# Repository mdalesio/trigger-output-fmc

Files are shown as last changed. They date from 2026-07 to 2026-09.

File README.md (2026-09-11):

# Trigger Output FMC

A single width HPC FMC board which provides 16 low jitter TTL outputs,
along with two Si5394 jitter cleaners with outputs connected to the MGTREF capable
when matched with the [LBL Marble](https://github.com/BerkeleyLab/Marble) FMC carrier.

This design is Open Hardware created by Osprey DCS and published under the terms of the
[CERN Open Hardware Licence Version 2 - Strongly Reciprocal](cern_ohl_s_v2.txt) license.

This repository contains KiCad 9.0.4 design files.

- [Data sheet](datasheet.md)
- [Current generated](https://osprey-dcs.github.io/trigger-output-fmc/)
  - [Schematic](https://osprey-dcs.github.io/trigger-output-fmc/trigger-output-fmc-schematic.pdf)
  - [BoM](https://osprey-dcs.github.io/trigger-output-fmc/trigger-output-fmc-bom.csv)
  - [STeP model](https://osprey-dcs.github.io/trigger-output-fmc/3D/trigger-output-fmc-3D.step)

## Block Diagram

Block diagra

## Status

Revision 1.0 produced and tested.

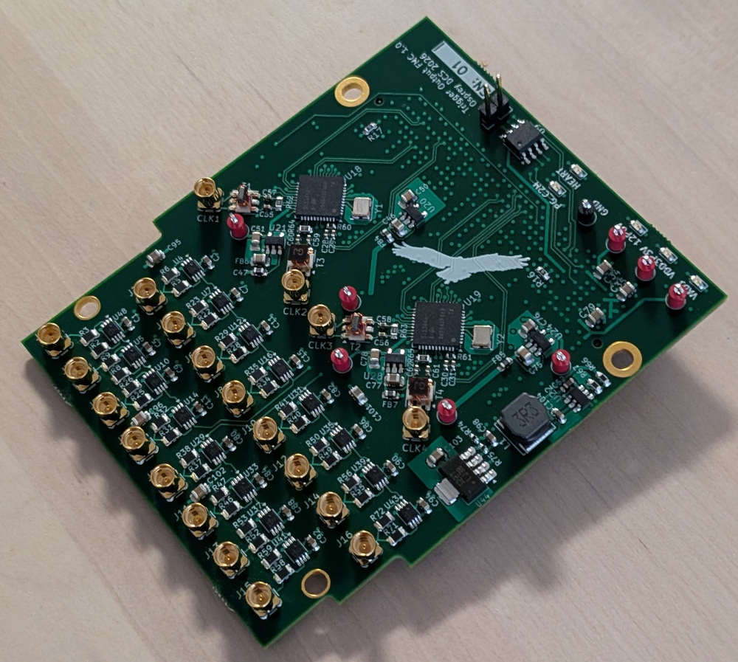
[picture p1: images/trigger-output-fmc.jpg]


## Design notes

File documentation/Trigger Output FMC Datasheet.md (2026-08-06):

# Trigger Output FMC Datasheet Draft
## Board Overview
The Trigger Output FMC board is a standard VITA 57.1 FMC HPC form factor board. [^1]
The board provides 2 independent Skyworks Solutions Si5394 Jitter Cleaners that recieve clocks though the FMC's M2C clock lines. Each Si5394 then outputs 4 copies of the recovered clock; 1 to the FMC's MGT clock, 1 to a FMC's C2M clock and 2 to SMA test ports on the board. The board has sixteen 50 ohm drive TTL-compatible digital outputs designed for low jitter. The outputs are provided as MMCX coaxial connectors.

[^1]:  The board can be used in a VITA 57.1 FMC LPC application but is limited to a single clock/timing domain. 
## Key components

- Skyworks Solutions Si5394 Jitter Attenuator
	- Ultra-low phase jitter of 100 fs RMS
	- Input frequency range - 8 kHz to 750 MHz
	- Output frequency range - 100 Hz to 1028 MHz
- Texas Instruments TLV3601 High-Speed Comparator
	- 4 ps RMS Jitter over 10Hz – 50MHz
- Texas Instruments SN74LVC2G126 Dual Bus Buffer Gate With 3-State Outputs
	- Can drive 50 ohm back-terminated TTL loads [^2]

[^2]:  See PubMed Central article PMC8342968 [link](https://pmc.ncbi.nlm.nih.gov/articles/PMC8342968/)
## Board Architecture
![[BlockDiagram.png|501]]

## Technical Specifications
### Nominal Performance
Channel-to-Channel Output Jitter: < 20pSec RMS
Event Clock Frequency: 50MHz - 250MHz;
16x SMA connectors; 50Ω drive capable; LVTTL

### Absolute Performance
Ambient Temperature: 0°C - 40°C
Digital Output drive current: 100mA max
Event Clock Rate: 50MHz - 250MHz
Event Bitrate: 1Gbps - 5Gbps
Number of user-configurable events: 255

## To include at a later date
- Nominal Testing data
- ? Theory of Operation for Output trigger
- ? Specifications for on-board power switcher and LDOs

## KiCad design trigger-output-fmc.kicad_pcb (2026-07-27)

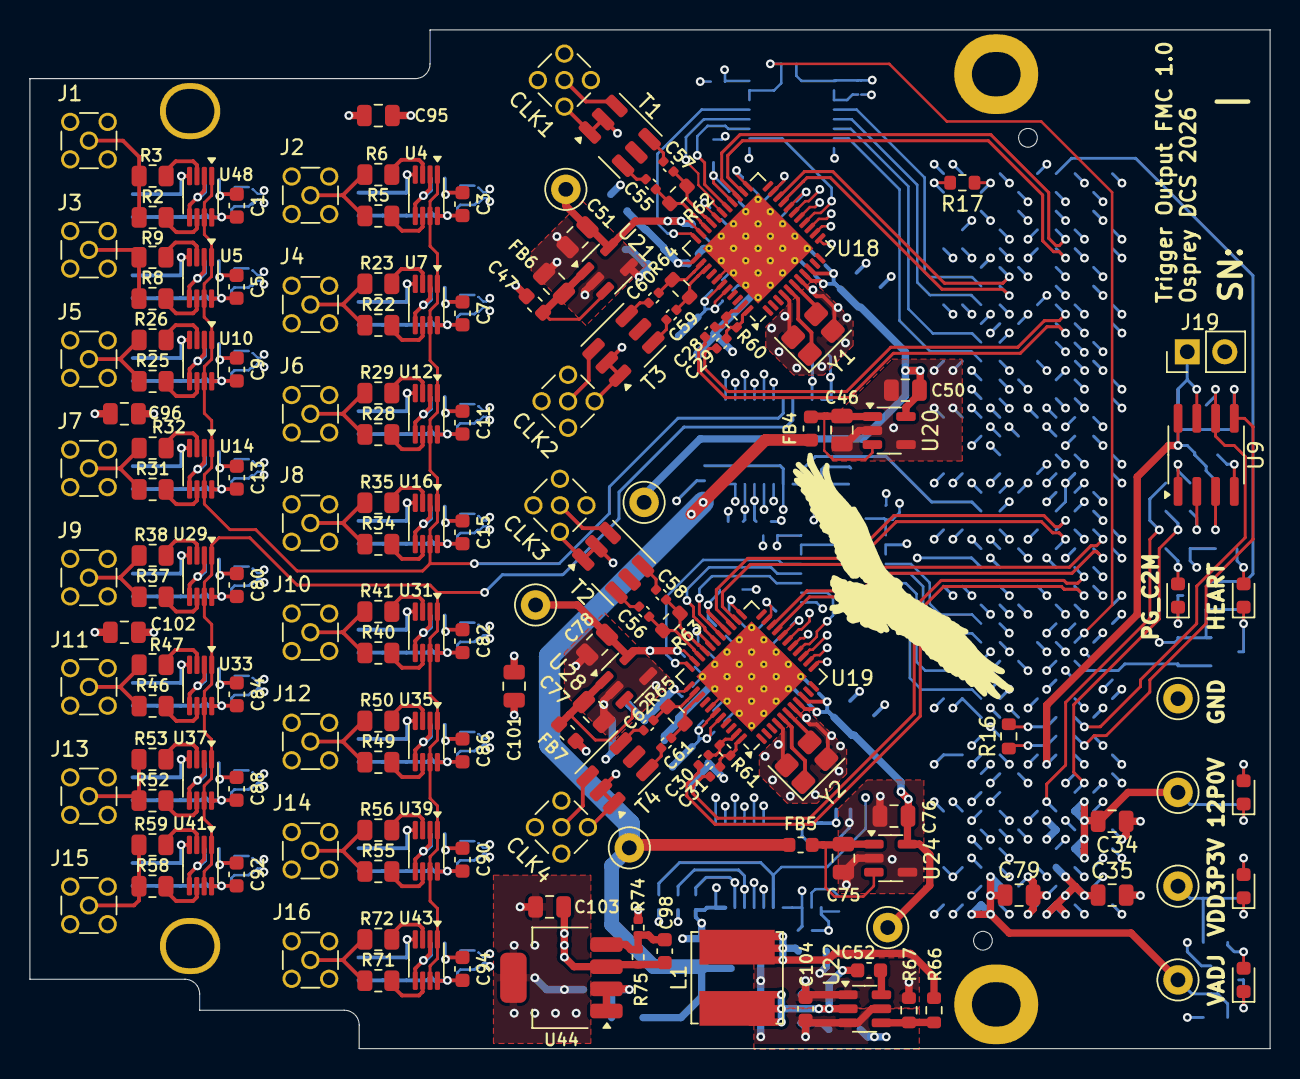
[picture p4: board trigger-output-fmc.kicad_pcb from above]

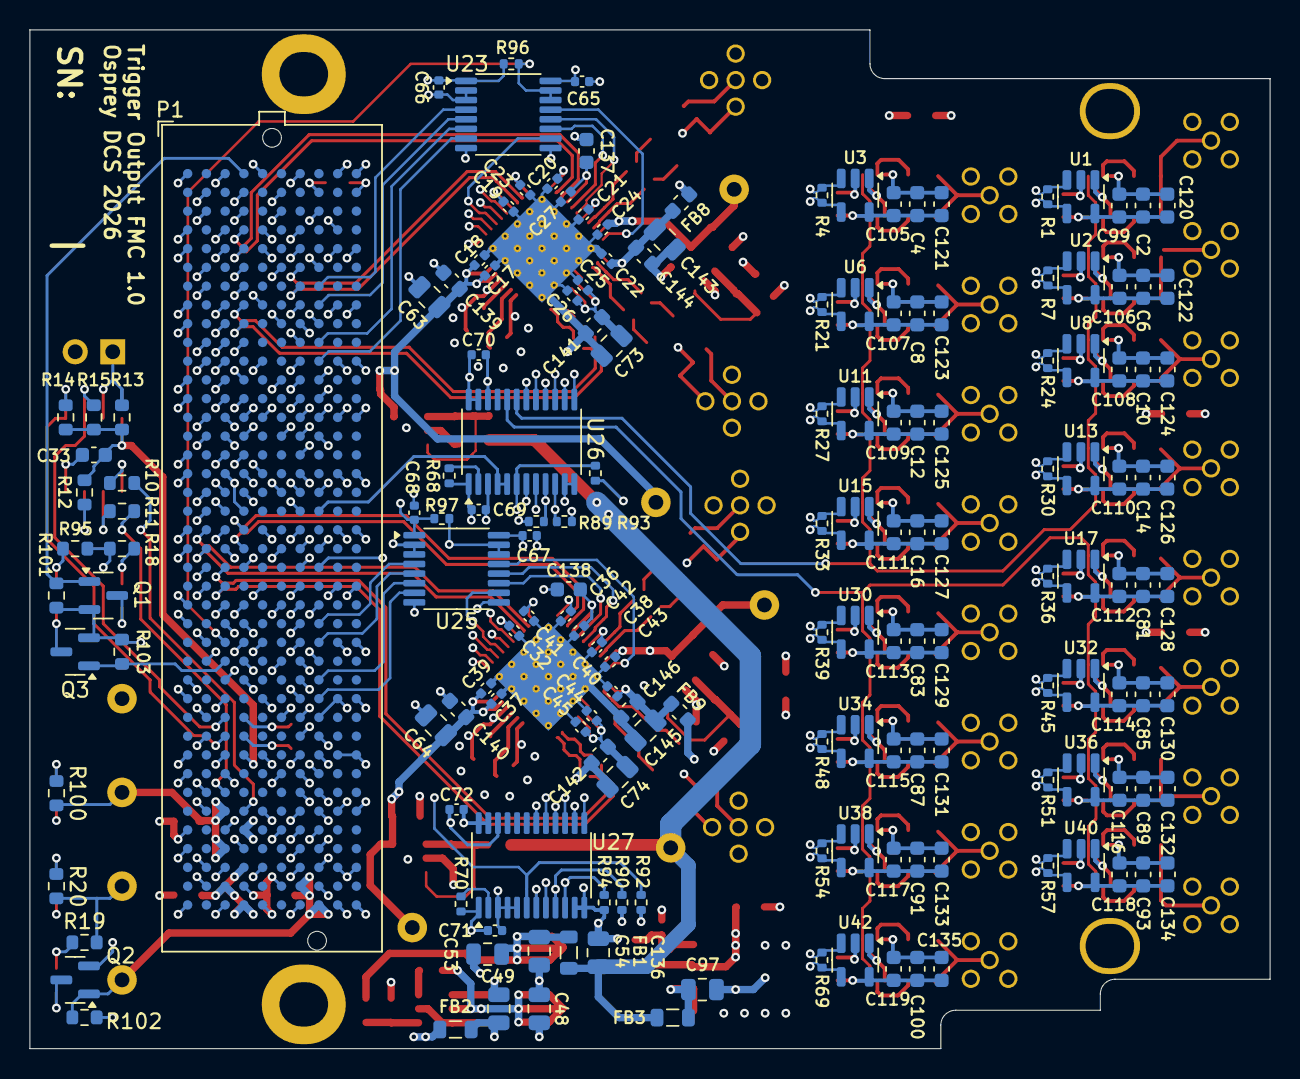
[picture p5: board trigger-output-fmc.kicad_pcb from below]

Board: 8 copper layers, 84.0 x 69.0 mm, 335 parts (168 on the bottom side), 226 nets.

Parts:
C1, C2, C3, C4, C5, C6, C7, C8, C9, C10, C11, C12, C13, C14, C15, C16, C52, C80, C81, C82, C83, C84, C85, C86, C87, C88, C89, C90, C91, C92, C93, C94, C100, C104: 100nF; C_0603_1608Metric
C17, C18, C19, C20, C21, C22, C23, C24, C25, C26, C27, C28, C29, C30, C31, C32, C36, C37, C38, C39, C40, C41, C42, C43, C44, C45, C55, C56, C57, C58, C59, C60, C61, C62, C65, C66, C67, C68, C69, C70, C71, C72: 100nF; C_0402_1005Metric
C33, C120, C121, C122, C123, C124, C125, C126, C127, C128, C129, C130, C131, C132, C133, C134, C135, C137, C138, C139, C140, C141, C142, C144, C146: 1uF; C_0603_1608Metric
C34, C35, C53, C54, C79, C136: 22uF; C_0805_2012Metric
C46, C47, C48, C49, C50, C51, C63, C64, C73, C74, C75, C76, C77, C78, C95, C96, C97, C101, C102, C103, C143, C145: 10uF; C_0805_2012Metric
C98: 62pF; C_0603_1608Metric
C99, C105, C106, C107, C108, C109, C110, C111, C112, C113, C114, C115, C116, C117, C118, C119: 10nF; C_0603_1608Metric
CLK1, CLK2, CLK3, CLK4: MMCX; MMCX_Molex_73415-1471_Vertical
D1, D2, D3, D4, D5: Green; LED_0603_1608Metric
FB1, FB2, FB3: 300@100MHz; L_0805_2012Metric
FB4, FB5, FB6, FB7, FB8, FB9: 120@100MHz; L_0603_1608Metric
H1, H2: MountingHole; MountingHole_3.0mm_M2.5_Pad_3.3mm_UniversalMarbleSlot
H3, H4: MountingHole; MountingHole_3.0mm_3.8mm_Pad_3.3mm_UniversalMarbleSlot
J1, J2, J3, J4, J5, J6, J7, J8, J9, J10, J11, J12, J13, J14, J15, J16: MMCX; MMCX_Molex_73415-1471_Vertical
J19: WP Jumper; PinHeader_1x02_P2.54mm_Vertical
L1: SRN6045TA-3R3Y; L_Bourns_SRN6045TA
Logo1: Osprey Logo; Logo_2X
P1: ASP-134488-01; Samtec_FMC_ASP-134602-01_10x40_P1.27mm_Vertical
Q1, Q2, Q3: FDN335N; SOT-23
R1, R4, R7, R21, R24, R27, R30, R33, R36, R39, R45, R48, R51, R54, R57, R60, R61, R69: 100R; R_0402_1005Metric
R2, R3, R5, R6, R8, R9, R22, R23, R25, R26, R28, R29, R31, R32, R34, R35, R37, R38, R40, R41, R46, R47, R49, R50, R52, R53, R55, R56, R58, R59, R71, R72: 88.7R; R_0805_2012Metric
R10, R11, R12, R14, R15: 4.75k; R_0603_1608Metric
R13: 11.5k; R_0603_1608Metric
R16, R17: 0R; R_0603_1608Metric
R18, R19, R20, R95: 1k; R_0603_1608Metric
R62, R63, R64, R65: 100R; R_0603_1608Metric
R66: 107k; R_0603_1608Metric
R67: 17.4k; R_0603_1608Metric
R68, R70, R89, R90, R91, R92, R93, R94, R96, R97: 4.75k; R_0402_1005Metric
R74: 18k; R_0402_1005Metric
R75: 56k; R_0402_1005Metric
R100: 8.2k; R_0603_1608Metric
R101, R102, R103: 100k; R_0603_1608Metric
T1, T2, T3, T4: TCM2-43X+; Mini-Circuits_DB1627_rounded_pads
TP1: Keystone5001; TestPoint_Keystone_5000-5004_Miniature
TP2, TP3, TP4, TP5, TP6, TP7, TP8, TP9: Keystone5000; TestPoint_Keystone_5000-5004_Miniature
U1, U2, U3, U6, U8, U11, U13, U15, U17, U30, U32, U34, U36, U38, U40, U42: TLV3601; SOT-23-5
U4, U5, U7, U10, U12, U14, U16, U29, U31, U33, U35, U37, U39, U41, U43, U48: SN74LVC2G126; VSSOP-8_2.3x2mm_P0.5mm
U9: AT24C64D; SOIC-8_3.9x4.9mm_P1.27mm
U18, U19: SI5394; QFN-44-1EP_7x7mm_P0.5mm_EP5.2x5.2mm_ThermalVias
U20, U24: TLV75733PDBV; SOT-23-5
U21, U28: TLV75718PDBV; SOT-23-5
U22: TPS563200; SOT-23-6
U23, U25: 74AVC4T245; TSSOP-16_4.4x5mm_P0.65mm
U26, U27: 74LVC8T245; TSSOP-24_4.4x7.8mm_P0.65mm
U44: LP3855EMP-ADJ/NOPB; SOT-223-5
Y1, Y2: CX3225SB48000D0FPJC1; Crystal_SMD_Abracon_ABM8AIG-4Pin_3.2x2.5mm

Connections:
3P3VAUX: C33.1, P1.D32, R12.1, R13.1, R14.1, R15.1, U9.8 (VCC)
+12V_FMC: C34.1, FB2.1, P1.C35, P1.C37, R100.2, TP2.1
/Digital IO/D_Output0.N: P1.G13, R1.2, U1.4 (-)
/Digital IO/D_Output0.P: P1.G12, R1.1, U1.3 (+)
/Digital IO/D_Output1.N: P1.H14, R4.2, U3.4 (-)
/Digital IO/D_Output1.P: P1.H13, R4.1, U3.3 (+)
/Digital IO/D_Output2.N: P1.G16, R7.2, U2.4 (-)
/Digital IO/D_Output2.P: P1.G15, R7.1, U2.3 (+)
/Digital IO/D_Output3.N: P1.D15, R21.2, U6.4 (-)
/Digital IO/D_Output3.P: P1.D14, R21.1, U6.3 (+)
/Digital IO/D_Output4.N: P1.C15, R24.2, U8.4 (-)
/Digital IO/D_Output4.P: P1.C14, R24.1, U8.3 (+)
/Digital IO/D_Output5.N: P1.G19, R27.2, U11.4 (-)
/Digital IO/D_Output5.P: P1.G18, R27.1, U11.3 (+)
/Digital IO/D_Output6.N: P1.D18, R30.2, U13.4 (-)
/Digital IO/D_Output6.P: P1.D17, R30.1, U13.3 (+)
/Digital IO/D_Output7.N: P1.C19, R33.2, U15.4 (-)
/Digital IO/D_Output7.P: P1.C18, R33.1, U15.3 (+)
/Digital IO/D_Output8.N: P1.G22, R36.2, U17.4 (-)
/Digital IO/D_Output8.P: P1.G21, R36.1, U17.3 (+)
/Digital IO/D_Output9.N: P1.G28, R39.2, U30.4 (-)
/Digital IO/D_Output9.P: P1.G27, R39.1, U30.3 (+)
/Digital IO/D_Output10.N: P1.G31, R45.2, U32.4 (-)
/Digital IO/D_Output10.P: P1.G30, R45.1, U32.3 (+)
/Digital IO/D_Output11.N: P1.H32, R48.2, U34.4 (-)
/Digital IO/D_Output11.P: P1.H31, R48.1, U34.3 (+)
/Digital IO/D_Output12.N: P1.G34, R51.2, U36.4 (-)
/Digital IO/D_Output12.P: P1.G33, R51.1, U36.3 (+)
/Digital IO/D_Output13.N: P1.H35, R54.2, U38.4 (-)
/Digital IO/D_Output13.P: P1.H34, R54.1, U38.3 (+)
/Digital IO/D_Output14.N: P1.H38, R57.2, U40.4 (-)
/Digital IO/D_Output14.P: P1.H37, R57.1, U40.3 (+)
/Digital IO/D_Output15.N: P1.G37, R69.2, U42.4 (-)
/Digital IO/D_Output15.P: P1.G36, R69.1, U42.3 (+)
/Digital IO/OE_A: U4.1 (1OE), U4.7 (2OE), U5.1 (1OE), U5.7 (2OE), U7.1 (1OE), U7.7 (2OE), U10.1 (1OE), U10.7 (2OE), U12.1 (1OE), U12.7 (2OE), U14.1 (1OE), U14.7 (2OE), U16.1 (1OE), U16.7 (2OE), U26.19 (B3), U48.1 (1OE), U48.7 (2OE)
/Digital IO/OE_B: U26.20 (B2), U29.1 (1OE), U29.7 (2OE), U31.1 (1OE), U31.7 (2OE), U33.1 (1OE), U33.7 (2OE), U35.1 (1OE), U35.7 (2OE), U37.1 (1OE), U37.7 (2OE), U39.1 (1OE), U39.7 (2OE), U41.1 (1OE), U41.7 (2OE), U43.1 (1OE), U43.7 (2OE)
/Digital IO/Switched_5P45V: C136.1, FB1.2, FB3.1, FB4.1, FB5.1, TP8.1
/Digital IO/VCC: C1.2, C2.2, C3.2, C4.2, C5.2, C6.2, C7.2, C8.2, C9.2, C10.2, C11.2, C12.2, C13.2, C14.2, C15.2, C16.2, C80.2, C81.2, C82.2, C83.2, C84.2, C85.2, C86.2, C87.2, C88.2, C89.2, C90.2, C91.2, C92.2, C93.2, C94.2, C95.1, C96.1, C98.1, C99.2, C100.2, C101.1, C102.1, C103.1, C105.2, C106.2, C107.2, C108.2, C109.2, C110.2, C111.2, C112.2, C113.2, C114.2, C115.2, C116.2, C117.2, C118.2, C119.2, C120.2, C121.2, C122.2, C123.2, C124.2, C125.2, C126.2, C127.2, C128.2, C129.2, C130.2, C131.2, C132.2, C133.2, C134.2, C135.2, R75.2, U1.5 (V+), U2.5 (V+), U3.5 (V+), U4.8 (V_{CC}), U5.8 (V_{CC}), U6.5 (V+), U7.8 (V_{CC}), U8.5 (V+), U10.8 (V_{CC}), U11.5 (V+), U12.8 (V_{CC}), U13.5 (V+), U14.8 (V_{CC}), U15.5 (V+), U16.8 (V_{CC}), U17.5 (V+), U29.8 (V_{CC}), U30.5 (V+), U31.8 (V_{CC}), U32.5 (V+), U33.8 (V_{CC}), U34.5 (V+), U35.8 (V_{CC}), U36.5 (V+), U37.8 (V_{CC}), U38.5 (V+), U39.8 (V_{CC}), U40.5 (V+), U41.8 (V_{CC}), U42.5 (V+), U43.8 (V_{CC}), U44.3 (Vout), U48.8 (V_{CC})
/Digital IO/out_buffer0/Out: J1.1 (In), R2.2, R3.2
/Digital IO/out_buffer1/Out: J2.1 (In), R5.2, R6.2
/Digital IO/out_buffer2/Out: J3.1 (In), R8.2, R9.2
/Digital IO/out_buffer3/Out: J4.1 (In), R22.2, R23.2
/Digital IO/out_buffer4/Out: J5.1 (In), R25.2, R26.2
/Digital IO/out_buffer5/Out: J6.1 (In), R28.2, R29.2
/Digital IO/out_buffer6/Out: J7.1 (In), R31.2, R32.2
/Digital IO/out_buffer7/Out: J8.1 (In), R34.2, R35.2
/Digital IO/out_buffer8/Out: J9.1 (In), R37.2, R38.2
/Digital IO/out_buffer9/Out: J10.1 (In), R40.2, R41.2
/Digital IO/out_buffer10/Out: J11.1 (In), R46.2, R47.2
/Digital IO/out_buffer11/Out: J12.1 (In), R49.2, R50.2
/Digital IO/out_buffer12/Out: J13.1 (In), R52.2, R53.2
/Digital IO/out_buffer13/Out: J14.1 (In), R55.2, R56.2
/Digital IO/out_buffer14/Out: J15.1 (In), R58.2, R59.2
/Digital IO/out_buffer15/Out: J16.1 (In), R71.2, R72.2
/FMC/Cleaned_CLK_0.N: P1.G7, U18.19 (~OUT0)
/FMC/Cleaned_CLK_0.P: P1.G6, U18.20 (Out0)
/FMC/Cleaned_CLK_1.N: P1.D21, U19.24 (~OUT1)
/FMC/Cleaned_CLK_1.P: P1.D20, U19.25 (Out1)
/FMC/Cleaner_Fault_0.INTR: P1.H7, U23.4 (A1)
/FMC/Cleaner_Fault_0.LOL: P1.H10, U23.6 (A3)
/FMC/Cleaner_Fault_0.LOS_XO: P1.H8, U23.5 (A2)
/FMC/Cleaner_Fault_1.INTR: P1.H25, U25.4 (A1)
/FMC/Cleaner_Fault_1.LOL: P1.H28, U25.6 (A3)
/FMC/Cleaner_Fault_1.LOS_XO: P1.H26, U25.5 (A2)
/FMC/Cleaner_SPI_0.CLK: P1.C10, U26.8 (A6)
/FMC/Cleaner_SPI_0.CS: P1.G10, R89.1, U26.9 (A7)
/FMC/Cleaner_SPI_0.OE: P1.D12, R91.1, U26.6 (A4)
/FMC/Cleaner_SPI_0.SDI: P1.C11, U26.7 (A5)
/FMC/Cleaner_SPI_0.SDO: P1.H11, U23.7 (A4)
/FMC/Cleaner_SPI_1.CLK: P1.D24, U27.8 (A6)
/FMC/Cleaner_SPI_1.CS: P1.G25, R90.1, U27.9 (A7)
/FMC/Cleaner_SPI_1.OE: P1.D27, R92.1, U27.6 (A4)
/FMC/Cleaner_SPI_1.SDI: P1.D26, U27.7 (A5)
/FMC/Cleaner_SPI_1.SDO: P1.H29, U25.7 (A4)
/FMC/Cleaner_~OE_0: P1.C26, R96.1, U23.14 (OE), U23.15 (OE)
/FMC/Cleaner_~OE_1: P1.H22, R97.1, U25.14 (OE), U25.15 (OE)
/FMC/Cleaner_~RST_0: P1.G9, R93.2, U26.10 (A8)
/FMC/Cleaner_~RST_1: P1.G24, R94.2, U27.10 (A8)
/FMC/EEPROM_GA0: P1.C34, R11.1
/FMC/EEPROM_GA1: P1.D35, R10.1
/FMC/EEPROM_SCL: P1.C30, R15.2, U9.6 (SCL)
/FMC/EEPROM_SDA: P1.C31, R14.2, U9.5 (SDA)
/FMC/FMC_GBTCLK0.N: P1.D5, U18.24 (~OUT1)
/FMC/FMC_GBTCLK0.P: P1.D4, U18.25 (Out1)
/FMC/FMC_GBTCLK1.N: P1.B21, U19.19 (~OUT0)
/FMC/FMC_GBTCLK1.P: P1.B20, U19.20 (Out0)
/FMC/OE_Digital_Outputs: P1.H19, U26.4 (A2), U26.5 (A3)
/FMC/Recovered_CLK_0.N: C29.1, P1.D8
/FMC/Recovered_CLK_0.P: C28.1, P1.D9
/FMC/Recovered_CLK_1.N: C31.1, P1.C22
/FMC/Recovered_CLK_1.P: C30.1, P1.C23
/Jitter Cleaner0/Cleaned_CLK2.N: C57.1, R62.2, U18.30 (~OUT2)
/Jitter Cleaner0/Cleaned_CLK2.P: C55.1, R62.1, U18.31 (Out2)
/Jitter Cleaner0/Cleaned_CLK3.N: C60.1, R64.2, U18.35 (~OUT3)
/Jitter Cleaner0/Cleaned_CLK3.P: C59.1, R64.1, U18.36 (Out3)
/Jitter Cleaner0/Control.INTR: U18.33 (~INTR), U23.13 (B1)
/Jitter Cleaner0/Control.LOL: U18.27 (~LOL), U23.11 (B3)
/Jitter Cleaner0/Control.LOS_XO: U18.28 (~LOS_XAXB), U23.12 (B2)
/Jitter Cleaner0/Control.OE: U18.12 (~OE), U26.18 (B4)
/Jitter Cleaner0/Control.RST: U18.17 (~RST), U26.14 (B8)
/Jitter Cleaner0/Control.SPI_CLK: U18.14 (SCLK), U26.16 (B6)
/Jitter Cleaner0/Control.SPI_CS: U18.16 (A0/~CS), U26.15 (B7)
/Jitter Cleaner0/Control.SPI_SDI: U18.13 (SDA/SDIO), U26.17 (B5)
/Jitter Cleaner0/Control.SPI_SDO: U18.15 (A1/SDO), U23.10 (B4)
/Jitter Cleaner0/In0.N: C29.2, R60.2, U18.44 (~IN0)
/Jitter Cleaner0/In0.P: C28.2, R60.1, U18.43 (In0)
/Jitter Cleaner0/VDD: C23.1, C24.1, C25.1, C26.1, C51.1, C73.1, C141.1, TP5.1, U18.21 (VDD), U18.32 (VDD), U18.39 (VDD), U18.40 (VDD), U21.5 (OUT)
/Jitter Cleaner0/VDDA: C17.1, C18.1, C50.1, C63.1, C139.1, TP7.1, U18.8 (VDDA), U18.9 (VDDA), U20.5 (OUT)
/Jitter Cleaner1/Cleaned_CLK2.N: C58.1, R63.2, U19.30 (~OUT2)
/Jitter Cleaner1/Cleaned_CLK2.P: C56.1, R63.1, U19.31 (Out2)
/Jitter Cleaner1/Cleaned_CLK3.N: C62.1, R65.2, U19.35 (~OUT3)
/Jitter Cleaner1/Cleaned_CLK3.P: C61.1, R65.1, U19.36 (Out3)
/Jitter Cleaner1/Control.INTR: U19.33 (~INTR), U25.13 (B1)
/Jitter Cleaner1/Control.LOL: U19.27 (~LOL), U25.11 (B3)
/Jitter Cleaner1/Control.LOS_XO: U19.28 (~LOS_XAXB), U25.12 (B2)
/Jitter Cleaner1/Control.OE: U19.12 (~OE), U27.18 (B4)
/Jitter Cleaner1/Control.RST: U19.17 (~RST), U27.14 (B8)
/Jitter Cleaner1/Control.SPI_CLK: U19.14 (SCLK), U27.16 (B6)
/Jitter Cleaner1/Control.SPI_CS: U19.16 (A0/~CS), U27.15 (B7)
/Jitter Cleaner1/Control.SPI_SDI: U19.13 (SDA/SDIO), U27.17 (B5)
/Jitter Cleaner1/Control.SPI_SDO: U19.15 (A1/SDO), U25.10 (B4)
/Jitter Cleaner1/In0.N: C31.2, R61.2, U19.44 (~IN0)
/Jitter Cleaner1/In0.P: C30.2, R61.1, U19.43 (In0)
/Jitter Cleaner1/VDD: C41.1, C43.1, C44.1, C45.1, C74.1, C78.1, C142.1, TP9.1, U19.21 (VDD), U19.32 (VDD), U19.39 (VDD), U19.40 (VDD), U28.5 (OUT)
/Jitter Cleaner1/VDDA: C37.1, C39.1, C64.1, C76.1, C140.1, TP6.1, U19.8 (VDDA), U19.9 (VDDA), U24.5 (OUT)
GND: C1.1, C2.1, C3.1, C4.1, C5.1, C6.1, C7.1, C8.1, C9.1, C10.1, C11.1, C12.1, C13.1, C14.1, C15.1, C16.1, C17.2, C18.2, C19.2, C20.2, C21.2, C22.2, C23.2, C24.2, C25.2, C26.2, C27.2, C32.2, C33.2, C34.2, C35.2, C36.2, C37.2, C38.2, C39.2, C40.2, C41.2, C42.2, C43.2, C44.2, C45.2, C46.2, C47.2, C48.2, C49.2, C50.2, C51.2, C53.2, C54.2, C63.2, C64.2, C65.1, C66.1, C67.1, C68.1, C69.1, C70.1, C71.1, C72.1, C73.2, C74.2, C75.2, C76.2, C77.2, C78.2, C79.2, C80.1, C81.1, C82.1, C83.1, C84.1, C85.1, C86.1, C87.1, C88.1, C89.1, C90.1, C91.1, C92.1, C93.1, C94.1, C95.2, C96.2, C97.2, C99.1, C100.1, C101.2, C102.2, C103.2, C104.1, C105.1, C106.1, C107.1, C108.1, C109.1, C110.1, C111.1, C112.1, C113.1, C114.1, C115.1, C116.1, C117.1, C118.1, C119.1, C120.1, C121.1, C122.1, C123.1, C124.1, C125.1, C126.1, C127.1, C128.1, C129.1, C130.1, C131.1, C132.1, C133.1, C134.1, C135.1, C136.2, C137.2, C138.2, C139.2, C140.2, C141.2, C142.2, C143.2, C144.2, C145.2, C146.2, CLK1.2 (Ext), CLK2.2 (Ext), CLK3.2 (Ext), CLK4.2 (Ext), D3.1 (K), D5.1 (K), H1.1, H2.1, H3.1, H4.1, J1.2 (Ext), J2.2 (Ext), J3.2 (Ext), J4.2 (Ext), J5.2 (Ext), J6.2 (Ext), J7.2 (Ext), J8.2 (Ext), J9.2 (Ext), J10.2 (Ext), J11.2 (Ext), J12.2 (Ext), J13.2 (Ext), J14.2 (Ext), J15.2 (Ext), J16.2 (Ext), J19.2, P1.A1, P1.A4, P1.A5, P1.A8, P1.A9, P1.A12, P1.A13, P1.A16, P1.A17, P1.A20, P1.A21, P1.A24, P1.A25, P1.A28, P1.A29, P1.A32, P1.A33, P1.A36, P1.A37, P1.A40, P1.B2, P1.B3, P1.B6, P1.B7, P1.B10, P1.B11, P1.B14, P1.B15, P1.B18, P1.B19, P1.B22, P1.B23, P1.B26, P1.B27, P1.B30, P1.B31, P1.B34, P1.B35, P1.B38, P1.B39, P1.C1, P1.C4, P1.C5, P1.C8, P1.C9, P1.C12, P1.C13, P1.C16, P1.C17, P1.C20, P1.C21, P1.C24, P1.C25, P1.C28, P1.C29, P1.C32, P1.C33, P1.C36, P1.C38, P1.C40, P1.D2, P1.D3, P1.D6, P1.D7, P1.D10, P1.D13, P1.D16, P1.D19, P1.D22, P1.D25, P1.D28, P1.D37, P1.D39, P1.E1, P1.E4, P1.E5, P1.E8, P1.E11, P1.E14, P1.E17, P1.E20, P1.E23, P1.E26, P1.E29, P1.E32, P1.E35, P1.E38, P1.E40, P1.F2, P1.F3, P1.F6, P1.F9, P1.F12, P1.F15, P1.F18, P1.F21, P1.F24, P1.F27, P1.F30, P1.F33, P1.F36, P1.F39, P1.G1, P1.G4, P1.G5, P1.G8, P1.G11, P1.G14, P1.G17, P1.G20, P1.G23, P1.G26, P1.G29, P1.G32, P1.G35, P1.G38, P1.G40, P1.H3, P1.H6, P1.H9, P1.H12, P1.H15, P1.H18, P1.H21, P1.H24, P1.H27, P1.H30, P1.H33, P1.H36, P1.H39, P1.J1, P1.J4, P1.J5, P1.J8, P1.J11, P1.J14, P1.J17, P1.J20, P1.J23, P1.J26, P1.J29, P1.J32, P1.J35, P1.J38 (J39), P1.J40, P1.K1, P1.K2, P1.K5, P1.K8, P1.K11, P1.K14, P1.K17, P1.K20, P1.K23, P1.K26, P1.K29, P1.K32, P1.K35, P1.K38, P1.K40, Q1.2 (S), Q2.2 (S), Q3.2 (S), R17.2, R67.2, R74.1, R93.1, R94.1, R101.1, R102.1, R103.1, T1.1 (PRI), T1.2 (PRI), T2.1 (PRI), T2.2 (PRI), T3.1 (PRI), T3.2 (PRI), T4.1 (PRI), T4.2 (PRI), TP1.1, U1.2 (V-), U2.2 (V-), U3.2 (V-), U4.4 (GND), U5.4 (GND), U6.2 (V-), U7.4 (GND), U8.2 (V-), U9.4 (GND), U10.4 (GND), U11.2 (V-), U12.4 (GND), U13.2 (V-), U14.4 (GND), U15.2 (V-), U16.4 (GND), U17.2 (V-), U18.38 (I2C_SEL), U18.45 (GND_PAD), U19.38 (I2C_SEL), U19.45 (GND_PAD), U20.2 (GND), U20.4 (NC), U21.2 (GND), U21.4 (NC), U22.1 (GND), U23.2 (1DIR), U23.3 (2DIR), U23.8 (GND), U23.9 (GND), U24.2 (GND), U24.4 (NC), U25.2 (1DIR), U25.3 (2DIR), U25.8 (GND), U25.9 (GND), U26.3 (A1), U26.11 (GND), U26.12 (GND), U26.13 (GND), U26.22 (OE), U27.3 (A1), U27.4 (A2), U27.5 (A3), U27.11 (GND), U27.12 (GND), U27.13 (GND), U27.22 (OE), U28.2 (GND), U28.4 (NC), U29.4 (GND), U30.2 (V-), U31.4 (GND), U32.2 (V-), U33.4 (GND), U34.2 (V-), U35.4 (GND), U36.2 (V-), U37.4 (GND), U38.2 (V-), U39.4 (GND), U40.2 (V-), U41.4 (GND), U42.2 (V-), U43.4 (GND), U44.5 (GND), U48.4 (GND)
Heartbeat_LED: P1.C27, Q3.1 (G), R103.2
unnamed: C53.1, C54.1, FB1.1, L1.2, R66.1
unnamed: CLK1.1 (In), T1.3 (PRI_DOT)
unnamed: CLK2.1 (In), T3.3 (PRI_DOT)
unnamed: CLK3.1 (In), T2.3 (PRI_DOT)
unnamed: CLK4.1 (In), T4.3 (PRI_DOT)
unnamed: D1.2 (A), R18.1
unnamed: D1.1 (K), Q1.3 (D)
unnamed: D2.2 (A), R19.1
unnamed: D2.1 (K), Q2.3 (D)
unnamed: D3.2 (A), R20.1
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

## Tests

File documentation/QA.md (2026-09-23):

# Trigger Output FMC Quality Assurance Procedure
## Purpose
The purpose of this document is to have a consistent unified way each Board is tested before deployment. This procedure will be updated periodically to improve QA of the boards.

## Equipment needed
* 2 x MMCX to SMA Cables
* 2 x SMA to BNC adapters
* 1 x SMA to SMA Cable
* Multimeter (Fluke 115 or better)
* Triple output Benchtop Power Supply
* 2 x FMC Power breakout module [link](https://www.iamelectronic.com/shop/produkt/fpga-mezzanine-card-fmc-power-module/)
* Marble Testing Chassis
* PC to run IOC and Phoebus

***
***
<form onsubmit="return false">
## Procedure

### QA Metadata
* **Board Serial Number:** <input type="text" placeholder="e.g., SN-1042">
* **PCB Revision:** <input type="text" placeholder="e.g., Rev B">

### Visual Inspection
Check visual for any board defects. If the board has come back from rework look at the reworked areas carefully under magnification for any shorts etc.

Areas to check with extra scrutiny are around the clock jitter cleaner components.

- [<input type="checkbox">] **Visual Inspection Complete**
  *Notes / Defects:* <input type="text" style="width: 80%;">

***

### Power Testing
Next the Board will be powered up in various ways to protect other testing hardware.

### Looking for Shorts to GND
Using the multimeter check that all voltage test points
have a resistance to board ground greater than 1kΩ.

| Silkscreened Label | Nominal Voltage | Measured Resistance (Ω) | Status |
| --- | --- | --- | --- |
| VDD3P3V | +3.3V | <input type="text"> | [<input type="checkbox">] Pass (>1kΩ) |
| VADJ | +2.5V | <input type="text"> | [<input type="checkbox">] Pass (>1kΩ) |
| 12P0V | +12V | <input type="text"> | [<input type="checkbox">] Pass (>1kΩ) |
| TP5 | +1.8V | <input type="text"> | [<input type="checkbox">] Pass (>1kΩ) |
| TP6 | +3.3V | <input type="text"> | [<input type="checkbox">] Pass (>1kΩ) |
| TP7 | +3.3V | <input type="text"> | [<input type="checkbox">] Pass (>1kΩ) |
| TP8 | +5.45V | <input type="text"> | [<input type="checkbox">] Pass (>1kΩ) |
| TP9 | +1.8V | <input type="text"> | [<input type="checkbox">] Pass (>1kΩ) |

  - [<input type="checkbox">] **Resistance Check Complete**

***

### 12V/3.3V/2.5V Power Testing
One at a time inject 12V, 3.3V & 2.5V using the voltage test points found on the board. Do this with a 1.5A current limit.

Note variance from nominal current if found.

| Rail | Nominal Expected | Measured Current | Notes / Variance |
| ---- | --- | --- | --- |
| 12V  | ~130mA | <input type="text"> | <input type="text"> |
| 3.3V | ~70mA | <input type="text"> | <input type="text"> |
| 2.5V | ~4mA | <input type="text"> | <input type="text"> |

- [<input type="checkbox">] **Individual Power Test Complete**

***

### FMC breakout Power Testing
Using a 3 output power supply and two FMC Power breakout modules: Power up all input power rails (12V/3.3V/2.5V) simultaneously.

Note variance from nominal current if found.

| Rail | Nominal Expected | Measured Current | Notes / Variance |
| ---- | --- | --- | --- |
| 12V  | ~130mA | <input type="text"> | <input type="text"> |
| 3.3V | ~70mA | <input type="text"> | <input type="text"> |
| 2.5V | ~4mA | <input type="text"> | <input type="text"> |

- [<input type="checkbox">] **FMC Breakout Power Test Complete**

***

### Power up with Marble
Attach a now power tested quartz to a **powered off** marble testing chassis.

- [<input type="checkbox">] Power up the testing chassis.
- [<input type="checkbox">] Start the IOC.
- [<input type="checkbox">] Ensure proper readback of diagnostic signals (voltage, etc.).
<br>
- [<input type="checkbox">] **Power Up with Marble Complete**

***

### EEPROM Programmed

Checkout the branch/revision appropriate to the PCB model to be programmed,
and edit `createEEPROMs.sh` with the appropriate serial numbers.

* **Git Revision / Commit Used:** <input type="text">
- [<input type="checkbox">] **EEPROM Programmed Complete**

***

### Signal Check - Clock Routing

* [<input type="checkbox">] Ensure the chassis under test has an EVR input at a nominal 125MHz provided by another chassis
* [<input type="checkbox">] Route received 125MHz through to the first jitter cleaner (U18) using FMC_LA_1 pin pair
    * [<input type="checkbox">] Ensure the System can now lock to FMC_GBTCLK0
    * [<input type="checkbox">] Using the FPGA console run 'fmon' to see the clock also on FMC_LA_0 signal pair
* [<input type="checkbox">] Route received 125MHz through to the first jitter cleaner (U18) using FMC_LA_18
    * [<input type="checkbox">] Ensure the System can now lock to FMC_GBTCLK1
    * [<input type="checkbox">] Using the FPGA console run 'fmon' to see the clock also on FMC_LA_17 signal pair
* [<input type="checkbox">] Ensure that each scenario locks

- [<input type="checkbox">] **Clock Routing Signal Check Complete**

***

### Signal Check - Digital Outputs
- [<input type="checkbox">] For each Digital Output set up and send an event stream turning all outputs on and off at 1Hz.
- [<input type="checkbox">] Force 0/1
- [<input type="checkbox">] Look at each of the 16 outputs to ensure compliance.

**Channels Checked:**

| Channel | Status | Channel | Status |
| :---: | :---: | :---: | :---: |
| Ch 0  | [<input type="checkbox">] Pass | Ch 8  | [<input type="checkbox">] Pass |
| Ch 1  | [<input type="checkbox">] Pass | Ch 9  | [<input type="checkbox">] Pass |
| Ch 2  | [<input type="checkbox">] Pass | Ch 10 | [<input type="checkbox">] Pass |
| Ch 3  | [<input type="checkbox">] Pass | Ch 11 | [<input type="checkbox">] Pass |
| Ch 4  | [<input type="checkbox">] Pass | Ch 12 | [<input type="checkbox">] Pass |
| Ch 5  | [<input type="checkbox">] Pass | Ch 13 | [<input type="checkbox">] Pass |
| Ch 6  | [<input type="checkbox">] Pass | Ch 14 | [<input type="checkbox">] Pass |
| Ch 7  | [<input type="checkbox">] Pass | Ch 15 | [<input type="checkbox">] Pass |

- [<input type="checkbox">] **Digital Outputs Signal Check Complete**

***

## Start/Completion Validation

* **Tested Performed By:** <input type="text" placeholder="Inspector Name">
* **Date Initiated:** <input type="date">
* **Date Completed:** <input type="date">

### Final Result
Indicate a Pass/Fail if this performed with no deviations or waivers
* [<input type="radio" name="result" value="PASS">] **PASS** / [<input type="radio" name="result" value="FAIL">] **FAIL**

* **Deviations / Waivers / Comments:**

    <textarea rows="3" cols="60" placeholder="Notes..."></textarea>

* Record the git commit of **this QA procedure** in the Testing Log:

    <input type="text" placeholder="Git Commit...">

<div class="no-print">
<hr>
<button type="button" onclick="copyForSpreadsheet()" style="padding: 10px 20px; font-weight: bold; cursor: pointer; background-color: #0366d6; color: white; border: none; border-radius: 4px;">
  📋 Copy Row for Spreadsheet
</button>
<button type="button" onclick="window.print()" style="padding: 10px 20px; font-weight: bold; cursor: pointer; background-color: #0366d6; color: white; border: none; border-radius: 4px;">
  📄 Print / Save as PDF
</button>
<button type="reset" style="padding: 10px 20px; font-weight: bold; cursor: pointer; background-color: #0366d6; color: white; border: none; border-radius: 4px;">
  🗑️ Clear All Fields
</button>
<span id="copy-status" style="margin-left: 10px; color: #28a745; font-weight: bold;"></span>
</div>
</form>

<script>
function copyForSpreadsheet() {
  const data = [];

  function cleanCell(val) {
    if (val === null || val === undefined) return '';
    return String(val).replace(/[\r\n\t]+/g, ' ').trim();
  }

  // 1. Gather all form controls in DOM order
  const controls = document.querySelectorAll('input, textarea');

  controls.forEach(control => {
    // Skip radio buttons that aren't checked
    if (control.type === 'radio' && !control.checked) return;

    // Capture checkbox state
    if (control.type === 'checkbox') {
      data.push(control.checked ? 'PASS' : 'UNCHECKED');
      return;
    }

    // Capture text, date, textarea, and selected radio value
    data.push(cleanCell(control.value));
  });

  const tsvRow = data.join('\t');

  // 2. Robust Copy Mechanism
  if (navigator.clipboard && window.isSecureContext) {
    navigator.clipboard.writeText(tsvRow).then(showSuccess).catch(fallbackCopy);
  } else {
    fallbackCopy();
  }

  // Fallback clipboard copy mechanism for browser environments where the modern Async Clipboard API (navigator.clipboard.writeText) is unavailable or blocked—such as local file:// protocols, older browsers, or unsecure contexts (http://)
  function fallbackCopy() {
    const tempTextArea = document.createElement('textarea');
    tempTextArea.value = tsvRow;
    tempTextArea.style.position = 'fixed';
    tempTextArea.style.left = '-9999px';
    document.body.appendChild(tempTextArea);
    tempTextArea.select();
    try {
      document.execCommand('copy');
      showSuccess();
    } catch (err) {
      alert('Failed to copy: ' + err);
    }
    document.body.removeChild(tempTextArea);
  }

  function showSuccess() {
    const status = document.getElementById('copy-status');
    status.textContent = 'Copied to clipboard!';
    setTimeout(() => { status.textContent = ''; }, 3000);
  }
}
</script>

<style>
@media print {
  /* Hide procedural text, equipment, and instruction steps */
  .no-print, nav, header, footer {
    display: none !important;
  }

  /* Compact spacing for the printed summary page */
  body {
    font-size: 11pt;
    line-height: 1.2;
    color: #000;
  }

  /* Make inputs look like clean text instead of form fields */
  input[type="text"], input[type="date"], textarea {
    border: none !important;
    border-bottom: 1px solid #000 !important;
    background: transparent !important;
  }

  /* Ensure tables print cleanly without breaking across pages */
  table {
    page-break-inside: avoid;
    width: 100%;
    border-collapse: collapse;
  }
}
</style>

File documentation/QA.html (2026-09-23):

# Trigger Output FMC Quality Assurance Procedure

## Purpose

The purpose of this document is to have a consistent unified way each Board is tested before deployment. This procedure will be updated periodically to improve QA of the boards.

## Equipment needed

- 2 x MMCX to SMA Cables
- 2 x SMA to BNC adapters
- 1 x SMA to SMA Cable
- Multimeter (Fluke 115 or better)
- Triple output Benchtop Power Supply
- 2 x FMC Power breakout module link (https://www.iamelectronic.com/shop/produkt/fpga-mezzanine-card-fmc-power-module/)
- Marble Testing Chassis
- PC to run IOC and Phoebus

## Procedure

### QA Metadata

- Board Serial Number:
- PCB Revision:

### Visual Inspection

Check visual for any board defects. If the board has come back from rework look at the reworked areas carefully under magnification for any shorts etc.

Areas to check with extra scrutiny are around the clock jitter cleaner components.

- [] Visual Inspection Complete Notes / Defects:

### Power Testing

Next the Board will be powered up in various ways to protect other testing hardware.

### Looking for Shorts to GND

Using the multimeter check that all voltage test points have a resistance to board ground greater than 1kΩ.

Silkscreened Label | Nominal Voltage | Measured Resistance (Ω) | Status
VDD3P3V | +3.3V | | [] Pass (>1kΩ)
VADJ | +2.5V | | [] Pass (>1kΩ)
12P0V | +12V | | [] Pass (>1kΩ)
TP5 | +1.8V | | [] Pass (>1kΩ)
TP6 | +3.3V | | [] Pass (>1kΩ)
TP7 | +3.3V | | [] Pass (>1kΩ)
TP8 | +5.45V | | [] Pass (>1kΩ)
TP9 | +1.8V | | [] Pass (>1kΩ)

- [] Resistance Check Complete

### 12V/3.3V/2.5V Power Testing

One at a time inject 12V, 3.3V & 2.5V using the voltage test points found on the board. Do this with a 1.5A current limit.

Note variance from nominal current if found.

Rail | Nominal Expected | Measured Current | Notes / Variance
12V | ~130mA
3.3V | ~70mA
2.5V | ~4mA

- [] Individual Power Test Complete

### FMC breakout Power Testing

Using a 3 output power supply and two FMC Power breakout modules: Power up all input power rails (12V/3.3V/2.5V) simultaneously.

Note variance from nominal current if found.

Rail | Nominal Expected | Measured Current | Notes / Variance
12V | ~130mA
3.3V | ~70mA
2.5V | ~4mA

- [] FMC Breakout Power Test Complete

### Power up with Marble

Attach a now power tested quartz to a powered off marble testing chassis.

- [] Power up the testing chassis.
- [] Start the IOC.
- [] Ensure proper readback of diagnostic signals (voltage, etc.).
- [] Power Up with Marble Complete

### EEPROM Programmed

Checkout the branch/revision appropriate to the PCB model to be programmed, and edit createEEPROMs.sh with the appropriate serial numbers.

- Git Revision / Commit Used:
- [] EEPROM Programmed Complete

### Signal Check - Clock Routing

- [] Ensure the chassis under test has an EVR input at a nominal 125MHz provided by another chassis
- [] Route received 125MHz through to the first jitter cleaner (U18) using FMC_LA_1 pin pair
  - [] Ensure the System can now lock to FMC_GBTCLK0
  - [] Using the FPGA console run ‘fmon’ to see the clock also on FMC_LA_0 signal pair
- [] Route received 125MHz through to the first jitter cleaner (U18) using FMC_LA_18
  - [] Ensure the System can now lock to FMC_GBTCLK1
  - [] Using the FPGA console run ‘fmon’ to see the clock also on FMC_LA_17 signal pair
- [] Ensure that each scenario locks
- [] Clock Routing Signal Check Complete

### Signal Check - Digital Outputs

- [] For each Digital Output set up and send an event stream turning all outputs on and off at 1Hz.
- [] Force 0/1
- [] Look at each of the 16 outputs to ensure compliance.

Channels Checked:

Channel | Status | Channel | Status
Ch 0 | [] Pass | Ch 8 | [] Pass
Ch 1 | [] Pass | Ch 9 | [] Pass
Ch 2 | [] Pass | Ch 10 | [] Pass
Ch 3 | [] Pass | Ch 11 | [] Pass
Ch 4 | [] Pass | Ch 12 | [] Pass
Ch 5 | [] Pass | Ch 13 | [] Pass
Ch 6 | [] Pass | Ch 14 | [] Pass
Ch 7 | [] Pass | Ch 15 | [] Pass

- [] Digital Outputs Signal Check Complete

## Start/Completion Validation

- Tested Performed By:
- Date Initiated:
- Date Completed:

### Final Result

Indicate a Pass/Fail if this performed with no deviations or waivers * [] PASS / [] FAIL

- Deviations / Waivers / Comments:
- Record the git commit of this QA procedure in the Testing Log:

📋 Copy Row for Spreadsheet 📄 Print / Save as PDF 🗑️ Clear All Fields

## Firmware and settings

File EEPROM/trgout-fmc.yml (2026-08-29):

# IPMI EEPROM

BoardInfo:
  mfg_date_time: '2026-08-25 09:00:00'
  manufacturer: 'Osprey'
  product_name: 'TRG-OUT'
  serial_number: '001'
  part_number: 'v1.0'

MultirecordArea:
- type: DCLoad
  output_number: P1_12P0V
  nominal_voltage: 12000
  min_voltage: 11400
  max_voltage: 12600
  max_noise_pk2pk: 0
  min_current_load: 0
  max_current_load: 1200

- type: DCLoad
  output_number: P1_3P3V
  nominal_voltage: 3300
  min_voltage: 3120
  max_voltage: 3460
  max_noise_pk2pk: 0
  min_current_load: 0
  max_current_load: 700

- type: DCLoad
  output_number: P1_VADJ
  nominal_voltage: 2500
  min_voltage: 2425
  max_voltage: 2575
  max_noise_pk2pk: 0
  min_current_load: 0
  max_current_load: 500

- type: FmcMainDefinition
  module_size: double_width
  p1_connector_size: lpc
  p2_connector_size: lpc
  clock_direction: m2c
  p1_a_num_signals: 68
  p1_b_num_signals: 68
  p2_a_num_signals: 0
  p2_b_num_signals: 0
  p1_gbt_num_trcv: 0
  p2_gbt_num_trcv: 0
  tck_max_clock: 0

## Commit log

2026-07-24 Changes before submission
    - Added pours to Jitter Cleaner0/VDD & Jitter Cleane1/VDD on In3 Layer
    - Added knockout in planes on In2 layer under the XTAL shield
    - Changed setback of ground layer from 0.5mm to 0.3mm
    - This fixed some breaks in the ground plane with dense vias, and cleared the way for uninterrupted gnd under controlled traces.
    - Changed the 22uF 0805 XR7 16V cap to an instock 22uF 0805 XR7 25V
    - Changed the 1uF 0603 XR7 16V cap to an instock 1uF 0603 XR7 25V
    [Jitter_Cleaner.kicad_sch, Power.kicad_sch, diff_comp_out_buffer.kicad_sch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]
2026-07-27 updated some trace widths and zone definitions
    -removed all 0.3mm & 0.14mm traces.
    *Changed to other sizes
    - Added a zone keepout under Y1 on In3 layer
    [trigger-output-fmc.kicad_pcb]
2026-08-29 Custom DRC for long differential pairs
    Add netclass "LongDiff".
    [diff_comp_out_buffer.kicad_sch, fmc.kicad_sch]
2026-09-11 Revert "Custom DRC for long differential pairs"
    This reverts commit 0760aa09d8a0bb8050a5ed56794ba4887f6d972d.
    [diff_comp_out_buffer.kicad_sch, fmc.kicad_sch]
2026-09-23 Add clear button
    Added button for clearing fields
2026-09-23 Enhance button styles in QA.md
    Updated button styles for print and reset actions to improve UI consistency.
2026-09-23 Add textarea and button for QA notes and actions
2026-09-23 Refactor QA.md for channel status and button updates
    Updated the QA documentation to include a table format for channel status and improved button elements for better accessibility.

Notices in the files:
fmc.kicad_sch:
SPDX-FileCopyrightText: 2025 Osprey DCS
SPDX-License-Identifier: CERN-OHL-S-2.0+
